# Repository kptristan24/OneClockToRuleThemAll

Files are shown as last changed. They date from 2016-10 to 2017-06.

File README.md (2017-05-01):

# OneClockToRuleThemAll
Our Senior Capstone Project to make a Word Clock on a budget. Weekly updates can be found on the wiki!

The project source code can be found in the sub directory [source/library/clean](source/library/clean)

## Usage Instructions

1. Aquire Necessary Hardware:
  * Arduino Uno (Other ATMEGA328 based boards may work but will probably take tinkering)
  * DS3234 RTC Module
  * Programmible LED strip supported by DOTSTAR library
  * Buttons
  
2. Assemble Hardware:
  * Connect the arrangement of LED strips, the RTC, and at least 3 buttons
  * There are many possible arrangements with the avaliable pins but where you connect things can be set in software.

3. Setup Software:
  * Download and install the latest version of the Arduino IDE (as of this writing: v1.8.2)
  * Some operating systems may require adjusting permissions of the tty interface

4. Setup Code:
  * Download a copy of the subfolder: source/library/clean
  * Download a copy of the libraries folder: libraries
  * Load the source code in Arduino IDE and include the RTC library and the FastLED library.
  * Edit the #define statements at the top of buttons.h, timekeeping.h, and display.h to set the pins where hardware is connected.
  * Plug the board in and flash the software

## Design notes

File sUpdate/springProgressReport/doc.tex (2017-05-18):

\documentclass[onecolumn, draftclsnofoot,10pt, compsoc]{IEEEtran}
\usepackage{url}
\usepackage{setspace}
\usepackage{graphicx}
\usepackage{xcolor}
\usepackage{textcomp}
\usepackage{listings}
\usepackage{geometry}
\lstset{
	language=C,
	keywordstyle=\bfseries\ttfamily\color[rgb]{0,0,1},
	identifierstyle=\ttfamily,
	commentstyle=\color[rgb]{0.133,0.545,0.133},
	stringstyle=\ttfamily\color[rgb]{0.627,0.126,0.941},
	showstringspaces=false,
	basicstyle=\small,
	numberstyle=\footnotesize,
	numbers=left,
	stepnumber=1,
	numbersep=10pt,
	tabsize=8,
	breaklines=true,
	prebreak = \raisebox{0ex}[0ex][0ex]{\ensuremath{\hookleftarrow}},
	breakatwhitespace=false,
	aboveskip={1.5\baselineskip},
  columns=fixed,
  upquote=true,
  extendedchars=true
}
\renewcommand{\lstlistingname}{Code Example}

\graphicspath{ {./exPics} }
\geometry{textheight=9.5in, textwidth=7in}

% 1. Fill in these details
\def \CapstoneTeamName{     One Clock to Rule Them all}
\def \CapstoneTeamNumber{       57}
\def \GroupMemberOne{           Tasman Thenell}
\def \GroupMemberTwo{           Tristan Hari}
\def \GroupMemberThree{         Scott Metzsch}
\def \CapstoneProjectName{      One Clock to Rule Them all}
\def \CapstoneSponsorCompany{   Oregon State University}
\def \CapstoneSponsorPerson{        Dr. Victor Hsu}

% 2. Uncomment the appropriate line below so that the document type works

\def \DocType{		%Problem Statement
				%Requirements Document
				%Technology Review
				%Design Document
				Progress Report
				}

\newcommand{\NameSigPair}[1]{\par
\makebox[2.75in][r]{#1} \hfil   \makebox[3.25in]{\makebox[2.25in]{\hrulefill} \hfill        \makebox[.75in]{\hrulefill}}
\par\vspace{-12pt} \textit{\tiny\noindent
\makebox[2.75in]{} \hfil        \makebox[3.25in]{\makebox[2.25in][r]{Signature} \hfill  \makebox[.75in][r]{Date}}}}
% 3. If the document is not to be signed, uncomment the RENEWcommand below
\renewcommand{\NameSigPair}[1]{#1}

%%%%%%%%%%%%%%%%%%%%%%%%%%%%%%%%%%%%%%%
\begin{document}
\begin{titlepage}
    \pagenumbering{gobble}
    \begin{singlespace}
        %\includegraphics[height=4cm]{coe_v_spot1}
        \hfill
        % 4. If you have a logo, use this includegraphics command to put it on the coversheet.
        %\includegraphics[height=4cm]{CompanyLogo}
        \par\vspace{.2in}
        \centering
        \scshape{
            \huge CS Capstone \DocType \par
            {\large\today}\par
            \vspace{.5in}
            \textbf{\Huge\CapstoneProjectName}\par
            \vfill
            {\large Prepared for}\par
            \Huge \CapstoneSponsorCompany\par
            \vspace{5pt}
            {\Large\NameSigPair{\CapstoneSponsorPerson}\par}
            {\large Prepared by }\par
            Group\CapstoneTeamNumber\par
            % 5. comment out the line below this one if you do not wish to name your team
            %\CapstoneTeamName\par
            \vspace{5pt}
            {\Large
                \NameSigPair{\GroupMemberOne}\par
                \NameSigPair{\GroupMemberTwo}\par
                \NameSigPair{\GroupMemberThree}\par
            }
            \vspace{20pt}
        }
        \begin{abstract}
        % 6. Fill in your abstract
            The purpose of this document is to discuss the progress of the One Clock to Rule Them All project and what our team has done during the spring term.
Included is an explanation of each document updated during this period of time and a summary of the progress made during each week of the term.
In addition, this process is reflected in retrospective which discusses challenges and difficulties as well as progress.
        \end{abstract}
    \end{singlespace}
\end{titlepage}
\newpage
\pagenumbering{arabic}
\tableofcontents
% 7. uncomment this (if applicable). Consider adding a page break.
%\listoffigures
%\listoftables
\clearpage

% 8. now you write!
\section{Project Purpose and Goals}
The background of the product arises from the personal interest of our client, Victor Hsu.
While there are similar products already on the market, QWLock by Ziegert and Funk for example, these products suffer from high prices and low availability.
These items traditional occupy a designer market niche which doesn't allow most people to experience the ownership of one.
In addition to these problems, it is also difficult to track down a model that has english lettering, as Ziegert is based in Germany.

We are not the first group of people to be inspired by the unique aesthetic and function of the word clock.
There are plenty of DIY projects online that also attempt to solve the problems of price and availability.
While these projects have been a valuable source of insight for the project, they are often very complicated and considered outside the comfort level of our expected users.
The intention of this product is to improve upon the situation by making the creation of a word clock less expensive, simpler, or both.

The clock we are making will be completely self contained with a battery or wall plug being used to power the clock.
There will be a microcontroller that is used to control the LEDs on the display and interface with the RTC in order to provide accurate timekeeping capabilities.

On the side of the clock there will be 3 buttons that will be used to set the time on the clock and change features.
Each button provides a specific function depending on the software context.
An example of this system when a basic menu is being manipulated would have two buttons providing up and down scrolling and one button to select an option or submenu.

The microcontroller will be the central piece of hardware in our clock and have the software for running it embedded into it.
The RTC will be connected to the board through 6 ports and will be used to check the time periodically to verify that the time is still correct.
The LEDs will also be connected to the board and the microcontroller will send data to the LEDs that tell them which LEDs to light up.
Lastly the 4 buttons will be connected to the microcontroller to set time and access additional features added to the clock.

The clock will also provide a way for the user to set and edit alarms. While making an audible alarm wasn’t planned, user programmable alarms indicated by the display flashing are expected functionality.
Aside from that, all the other goals were simply that: it continues to operate in the normal range of temperature, at least a year straight, and is visible from 10-20 feet.

\section{Current State of project}

\subsection{Hardware}
In terms of hardware we have all of our electronic components working.
The Arduino Uno is working correctly and can communicate with the LEDs, RTC, and buttons.
The LEDs are all soldered together and have valid connections between the 12 strips.
We also have a power adapter with more amps that we are using to power both the board and LEDs.

In terms of the case hardware we are almost done with the case.
We have the 4 sides of the case cut to size with grooves cut for the front and back plate to slide in.
We have also stained these 4 sides.

\subsection{Software}
The current state of the software for the program is solid but needs more testing.
Due to difficulties relating to hardware assembly, large chunks of code have only been lightly tested.
That being said, feature completeness has been achieved and will be demonstrated during Expo.

The code is broken into two main components: the hardware abstractions and libraries, and example programs that use those libraries.
Each main hardware component (RTC, Buttons, and LEDs) are wrapped in abstractions which handle setting up these objects as well as facilitating ease of use.
Our example code is what presents the features described in our requirements to the user.

The core of the project is broken into a group of software libraries which are tied together in the main Arduino program loop.
These acts as the “operating system” of the clock from which different programs can be run, the running program can be changed, and alarms can trigger.

To get more detailed about this operating system comparison, each program for our system is a subclass of an abstract class called “state”.
All states share four common functions by which the operating system will interact with them.
The first of these functions is a constructor: a function which does any “run-once” setup for the program or state.

Three additional functions form the interface with between the operating system code and the running program: handleInput, runLogic, and drawFrame.
The first of these functions is tasked with dealing with user input.
The second function does any computing or processing work that needs to happen for the state.
The final function is tasked with updating the screen of the clock.
For some states this could be menu text, for others it could be the time in words, and for others it might be a digital time.

The second set of software written for our project is a set of example states.
These could be compared to Internet Explorer and MS Paint that come bundled with Windows.
These example states are a set of programs that run on top of the aforementioned set of abstractions which form the operating system for this product.

The example states (or programs) that are included in our project are geared towards meeting the software functionality requirements for our project.
Some of the states we have developed which will be shown off at expo are: normal word clock, digital clock, system menu, add/remove alarms, game of snake,  LED demo, and a triggered alarm.
Thanks to the high level abstraction offered by our hardware libraries, most of these states are relatively simple which was one of the goals of the project.

\subsection{Technology Review}
The technology review has been updated to reflect several changes in the project that have occured over the past two months.
The largest changes take the form of a change in the development board.
While the MPLABS Xpress board seemed like a good idea on paper, it didn't have much in the way of software support.
In addition to this, the documentation and code examples for the board were ranging from poor to nonexistant.

The new board chosen to replace it is an Arduino Uno.
This board has better software support and documentation by a very large margin.
This is documented in the Technology Review in the form of discussing the new board as well as the libraries that come with it.
Extensive research into libraries allowed development to progress more in two weeks than it had duing the six weeks prior.

\section{Remaining Work}
\subsection{Hardware}
Our remaining problem is that we are waiting for our final clock face cut from Kevin.
We should have started the prototyping process sooner to allow for more iterations of the case and clock face before we needed our final product.
Once we have the final test cut back from Kevin we will have all the hardware sections of the project completed.

\subsection{Software}
The largest remaining piece of work that needs to be done is debugging.
Various technical and cranial setbacks meant that we didn’t have a full set of the hardware assembled to test code on until somewhat recently.
Debugging is going well and is following the logical order of necessity: state manager first, display library second, time library third, and lastly button control.
That being said, all the core features are on course to be functional at Expo.

In addition to a scrolling text library, the code for static text needs to be finished.
This functionality allows the clock to show words of length four or less in fixed positions.
This was left until the end of development as scrolling text is significantly more complicated and static text can reuse most of the same code.

Another requested feature that won’t be complete for Expo is a color gradient generator.
This boils down to coming up with an algorithm that generates a unique color for the time of day.
The idea behind this capability is that the word clock (or other modes) can gradually shift through pleasant colors throughout the day.
The holdup here is an algorithm.
The function infrastructure is already in place.

Being able to change the simulated pace of time for the sake of demonstration is one feature we are rushing to complete before expo.
This will act as a wrapper around the get time functions in the clock so that we can accelerate the passage of time for the clock.
This would be useful for demonstrating alarms going off or the gradual change in color if that feature is ready by Friday.

Another item that remains on the “to-do” list is rewriting the alarm system to not rely on hardware alarms.
While using the hardware alarm feature on the Real Time Clock (RTC) can work fine, it would easier and cleaner to have alarms be handled in software.
This also frees the hardware alarms up for usage in project code without conflicting with clock functionality.
Another perk of this change would be that it makes it even simpler to port our project to a different RTC chip because we use less specific hardware features.

The last part of the project that needs to be completed before we turn our work over to our client is documentation.
Code interface has been commented to make it easy to interact with functions.
That being said, we need to produce a set of formal documentation about using our code as well as further documenting the example classes (programs) that run the basic clock functionality.
Documentation was set aside to get things ready for Expo which means it will need to be a top priority in the three remaining weeks after Expo.

\section{Impeding Factors}
Over the course of the project there were two major things that impeding progress for us.
The first of which is the original microcontroller we had.
The MPBLABXpress Evaluation board we started with looked appealing and had a nice demo example, upon further inspection we found that this was just a nice appearance.
Once we started looking into writing code to control a strip of LEDs we ran into many issues.
Large sections of the code is auto generated which made it difficult to understand and make edits to files.
Second the problem is that library integration was difficult to implement and we would be using multiple libraries to control the RTC and LEDs.
When we came to the conclusion that this board wasn’t going to work we decided to move to an Arduino Uno for our microcontroller.

The second main issue we had in our project was designing the case.
With all of us being CS students we have limited woodworking experience.
To get around this problem we created multiple prototypes and talked with people at lumber stores to learn about different techniques and wood we might use for the case.
With the multiple people and prototypes we made our final case has turned out great and has a nice finish and appearance.

\section{Code Samples}
\subsection{Scrolling Text}
\lstinputlisting[language=c++, caption=Scrolling text Example., captionpos=b]{codeExamples/demoState.cpp}
One of the key abstractions that powers the interface for the clock: scrolling text.
Our software supports two independent lines of text which can be set, cleared, and updated independently.
This was done in order to be able to show text that isn’t among the words cut into the clock faceplate.
One place this is crucial is for displaying menu text.
\vspace{5mm}
\subsection{Menu Code}
\lstinputlisting[language=c++, caption=Main Menu State., captionpos=b]{codeExamples/mainMenu.cpp}
Another core UI element in the menu.
For our system, a menu is composed of two sections: the menu title (displayed on the top row of text), and the menu options (displayed on the lower row).
Rather than having to right clusters of switch statements and other conditional logic every time a manu is needed, a menu item is provided.
This object does all the heavy lifting of displaying menus and handling user interaction.
\vspace{5mm}
\subsection{The "Operating System"}
\lstinputlisting[language=c++, caption=Core System Loop., captionpos=b]{codeExamples/clean.cpp}
Displayed above is the core code for running the clock.
A user of our software need not alter any of this, they only need to select the starting state of the clock.
The key pieces here are check for hardware signals (from buttons or RTC), run the current program, change the running program if required, and run cleanup to prepare for a new program.

\section{Project Pictures}
A few pictures from our development and work on the project.
\centering
\begin{figure}
\caption{Professional woodworking in progress}
 %natwidth=3024,natheight=4032
\end{figure}
\begin{figure}
\caption{Case parts prior to finishing}

\end{figure}
\begin{figure}
\caption{The scrolling text library showing "Hello" and "World"}
\vspace{2mm}

\end{figure}
\end{document}

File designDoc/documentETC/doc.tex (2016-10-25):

\documentclass[10pt,draftclsnofoot,onecolumn]{IEEEtran}
\newcommand{\namesigdate}[2][7cm]{%
\begin{minipage}{#1}
    #2 \vspace{1.0cm}\hrule\smallskip
    \small \textit{Signature}
    \vspace{1.0cm}\hrule\smallskip
    \small \textit{Date}
\end{minipage}
}
\usepackage{graphicx}
\usepackage{textcomp}
\graphicspath{ {} }
\begin{document}
\pagenumbering{gobble}
\title{One Clock To Rule Them All}
\author{Tristan Hari, Tasman Thenell, and Scott Metzsch}
\maketitle
\begin{abstract}
Historically, the wristwatch has had one of two faces, analog or digital. These
formats have provided a solid mix between function and fashion, but there are
many other possible ways of visually representing the concept of time. One
creative idea worth exploring is timekeeping through words and letters. The
basis of our capstone project is to investigate making such a clock with a
microcontroller, real time clock module, and a set of LED’s. We will combine
this physical base with a software library of our creation to power a word clock.
\end{abstract}
\IEEEpeerreviewmaketitle

\newpage
\pagenumbering{arabic}

\title{Problem Statement}
\section{Problem Background}
Timekeeping isn\textquotesingle t an advanced concept at a fundamental level. Since the first
cavepeople noticed that they had to shade their eyes from the sun differently
at various ``times'' of the day, humans have studied time. Throughout history
humans have created many different methods for tracking time. , each more
ostentatious than the last, for keeping time. Classic examples of the lengths
cultures have gone to track time include Stonehenge and Big Ben. While such
methods of timekeeping aren\textquotesingle t necessary, we still seek even more
interesting ways of telling time. One such example of this is the word clock. A
word clock has a face made out of a grid of letters. This grid is layed out such that
there are enough letters to create all words required for spelling out any given time
of day. While clocks following this idea already exist, most are overly complicated,
look chintzy, or are prohibitively expensive.

\section{Problem Solution}
We would like to address the problem of this type of time keeping solution not
being readily avaliable by creating a similar product using
off the shelf parts and our own custom software. The current concept for
implementation is to use a microcontroller, real time clock (RTC), and LED strips
with individually programmable lights to power the face of the clock. For the
casing/shell we will investigate the feasibility of using 3D printing, laser cutting,
or woodworking to create structural components. In addition to the hardware, we
will develop a software library to run on the microcontroller that supports
various modes of displaying time as well as providing any additional functionality
we have time to develop.

\section{Metrics for Completion}
In order to demonstrate completion of this project, we will meet the following requirements:
\begin{itemize}
  \item Establish a connection between a real time clock module and a
  microcontroller for the purpose of controlling a custom clock face.
  \item Design a grid of letters such that there are enough of each letter for displaying
  all of the words necessary for spelling out any time of day.
  \item Support for an alternate output mode for displaying the time in binary coded
  decimal (BCD) mode.
  \item Take at least one source of input to facilitate letting the user set the
  time on the clock.
\end{itemize}

\section{Stretch/Additional Goals}
If time permits, our group will explore additional features that would either
make the clock more robust or easier \quad to use. The following stretch goals have
already been discussed:
\begin{itemize}
  \item Wireless or bluetooth methods for setting or changing the clock remotely,
  possibly via a mobile app.
  \item Support alternate physical configurations or letter grid arrangements.
  \item Different view modes that use the eleven by eleven grid of letters as an
  eleven by eleven pixel low resolution screen.
\end{itemize}

\newpage
\newpage

\noindent \namesigdate{Victor Hsu} \hfill \namesigdate{Tristan Hari} \par
\vspace{2cm}
\noindent \namesigdate{Tasman Thenell} \hfill \namesigdate{Scott Metzsch}
\end{document}

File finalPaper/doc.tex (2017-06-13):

\documentclass[onecolumn, draftclsnofoot,10pt, compsoc]{IEEEtran}
\usepackage{graphicx}
\graphicspath{ {graphics/} }
\usepackage{url}
\usepackage{setspace}
\usepackage{xcolor}
\usepackage{textcomp}
\usepackage{listings}

\usepackage{geometry}
\geometry{textheight=9.5in, textwidth=7in}

\setcounter{secnumdepth}{4}
\setlength{\parindent}{0em}
\setlength{\parskip}{1em}

\setcounter{secnumdepth}{4}
\setlength{\parindent}{0em}
\setlength{\parskip}{1em}

\lstset{
		language=C,
		keywordstyle=\bfseries\ttfamily\color[rgb]{0,0,1},
		identifierstyle=\ttfamily,
		commentstyle=\color[rgb]{0.133,0.545,0.133},
		stringstyle=\ttfamily\color[rgb]{0.627,0.126,0.941},
		showstringspaces=false,
		basicstyle=\small,
		numberstyle=\footnotesize,
		numbers=left,
		stepnumber=1,
		numbersep=10pt,
		tabsize=8,
		breaklines=true,
		prebreak = \raisebox{0ex}[0ex][0ex]{\ensuremath{\hookleftarrow}},
		breakatwhitespace=false,
		aboveskip={1.5\baselineskip},
		columns=fixed,
		upquote=true,
		extendedchars=true
}
\renewcommand{\lstlistingname}{Code Example}

% 1. Fill in these details
\def \CapstoneTeamName{		One Clock to Rule Them all}
\def \CapstoneTeamNumber{		57}
\def \GroupMemberOne{			Tasman Thenell}
\def \GroupMemberTwo{			Tristan Hari}
\def \GroupMemberThree{			Scott Metzsch}
\def \CapstoneProjectName{		One Clock to Rule Them all}
\def \CapstoneSponsorCompany{	Oregon State University}
\def \CapstoneSponsorPerson{		Dr. Victor Hsu}

% 2. Uncomment the appropriate line below so that the document type works
\def \DocType{		%Problem Statement
				%Requirements Document
				%Technology Review
				%Design Document
				Final Progress Report
				}

\newcommand{\NameSigPair}[1]{\par
\makebox[2.75in][r]{#1} \hfil 	\makebox[3.25in]{\makebox[2.25in]{\hrulefill} \hfill		\makebox[.75in]{\hrulefill}}
\par\vspace{-12pt} \textit{\tiny\noindent
\makebox[2.75in]{} \hfil		\makebox[3.25in]{\makebox[2.25in][r]{Signature} \hfill	\makebox[.75in][r]{Date}}}}
% 3. If the document is not to be signed, uncomment the RENEWcommand below
\renewcommand{\NameSigPair}[1]{#1}

%%%%%%%%%%%%%%%%%%%%%%%%%%%%%%%%%%%%%%
\begin{document}
\begin{titlepage}
    \pagenumbering{gobble}
    \begin{singlespace}
    	%\includegraphics[height=4cm]{coe_v_spot1}
        \hfill
        % 4. If you have a logo, use this includegraphics command to put it on the coversheet.
        %\includegraphics[height=4cm]{CompanyLogo}
        \par\vspace{.2in}
        \centering
        \scshape{
            \huge CS Capstone \DocType \par
            {\large\today}\par
            \vspace{.5in}
            \textbf{\Huge\CapstoneProjectName}\par
            \vfill
            {\large Prepared for}\par
            \Huge \CapstoneSponsorCompany\par
            \vspace{5pt}
            {\Large\NameSigPair{\CapstoneSponsorPerson}\par}
            {\large Prepared by }\par
            Group\CapstoneTeamNumber\par
            % 5. comment out the line below this one if you do not wish to name your team
            %\CapstoneTeamName\par
            \vspace{5pt}
            {\Large
                \NameSigPair{\GroupMemberOne}\par
                \NameSigPair{\GroupMemberTwo}\par
                \NameSigPair{\GroupMemberThree}\par
            }
            \vspace{20pt}
        }
        \begin{abstract}
        % 6. Fill in your abstract
        	The purpose of this document is to discuss the final state of the One Clock to Rule Them All project.
Included is the original version of each  development document, the changes made to these documents, and weekly development summaries for the past nine months.
In addition, this document includes project usage information and hindsight gained from development.
        \end{abstract}
    \end{singlespace}
\end{titlepage}
\newpage
\pagenumbering{arabic}
\singlespacing
\tableofcontents
% 7. uncomment this (if applicable). Consider adding a page break.
%\listoffigures
%\listoftables
\clearpage
\onehalfspacing

\section{Introduction}

The One Clock to Rule Them All project grew out of a desire to make DIY word clocks easy to build, control, and customize.
The client behind this vision was Dr. Hsu, an Oregon State research faculty working in biophysics. Outside of his research work, Dr. Hsu is a DIY electronics hobbyist.
Within the wide range of popular electronics projects is the area of timekeeping, and within those projects lies the word clock.

The idea of making a word clock isn’t a new idea.
Word clocks have existed in several forms in the past including designs that have generic displays capable of showing any word, to matrix displays of composed of predefined letters which can only show specific words.
Our client found the second layout of interest and was inspired to build one.
And this is when a difficulty arose.

There are several existing sets of code for powering word clocks already on the internet.
The difficulty is that all the existing code is built for a specific set of hardware and the software isn’t very abstracted.
For comparison, existing implementations are typically composed of several hundred lines of code.
Our finished software library can run a word clock with only around a dozen lines of code more than an empty Arduino project file.

It was this goal of making the software experience of building a wordclock less painful, more abstracted, and more user friendly that Dr. Hsu came up with this Capstone project.
Once we were placed with this project, our development roles shook down to the following: Tasman Thenell was the primary code architect, Scott Metzsch became the lead materials engineer, and Tristan Hari was the primary external interactions manager.

The other indispensable honorary member of our development team was Dr. Hsu himself.
While it was never formally set up that he would be part of the team, there were many areas of the project outside of coding where his consulting was invaluable.
While each of us brought strengths to the table around code development, Dr. Hsu was deeply knowledge about most of the other parts of our project.
Our development was greatly accelerated by picking his brain about electronics, materials, and other physical parts of development several times each quarter. Without this assistance, it is doubtful that the project would have been finished in time or achieved the same level of quality.

\section{Requirements Document}
\subsubsection{Purpose}
Historically, the clock face has had one of two display modes, analog or digital.
These formats have provided a solid mix between function and fashion, but there are many
other possible ways of visually representing the concept of time. One creative idea worth
exploring is timekeeping through words and letters. Although some examples of this already
exist in the high end fashion market, such as QWLock or others, they are well outside the
price range of an average consumer. The purpose of our project is to provide a similar
product with much cheaper production.

\subsubsection{Scope}
The name of our product is tentatively “One Clock To Rule Them All”, or “The One Clock.”
The One Clock’s function will be, simply, to tell time. However the functionality of it is
defined as being able to creatively tell time through a grid of apparently random letters.
Time will be displayed in forms such as “It is half past twelve” or “it is one fifty.” The
user will be able to set the starting time using a button component on the clock. Something
that may be assumed as a regular clock function that our clock will not do, is that this clock
 is not centered around being an alarm/scheduler device. We do not intend to have any sound
 components and thusly any alarm system will be mostly moot.

\subsubsection{Definitions}
\begin{enumerate}
  \item Time - The abstract concept that our machine is keeping track of and displaying to the user
  \item Real Time Clock - A real time clock module is the hardware component that tracks the passage
  of time regardless of the state of the rest of the system.
  \item RTC - Acronym for Real Time Clock module.
  \item Microcontroller - The brains of the clock. This module interfaces between the hardware
  components, the RTC, LEDs and buttons, and processes the logic for all clock functionality.
  This includes tasks like updating the display and processing user input from the buttons.
  \item Programmable LED - A Light Emitting Diode that has variable levels of brightness and
  color output. Each module is individually programmable in terms of brightness and color.
  \item LED - Acronym for Light Emitting Diode. Within this project, the term LED will always
  be used to refer to a programmable light emitting diode.
  \item Display - The LED lit letters of the clock face in a grid arrangement are collectively
  called the display. This term will be used to refer to the visual
  \item Software Library - The set of control software running on the microcontroller which drives all display output.
  \item User Interface - A set of buttons by which the user controls and interacts with the clock.
  \item BCD - Acronym for Binary Coded Decimal.
  \item Binary Coded Decimal - A method for encoding decimal numbers and information via binary.
  \item USB - Acronym for Universal Serial Bus.
  \item Universal Serial Bus - A communications medium by which the device is programmed and  powered.
\end{enumerate}

\subsubsection{Overview}
The following subsections of this requirements document describe product specifications as follows.
subSection 2 explains the purpose, function, and form of the product in broad terms on a less
technical level. Building on that foundation, subSection 3 breaks the functional requirements
describe in subSection 2 into technical requirements and specifications.
    Both of the following subsections are intended for conveying the entire functional
scope of the Word Clock project but at different levels. subSection 2 provides an overview of the
project while subSection 3 pertains to exact requirements which requires a more technical working
knowledge of hardware and software design.

\subsection{Overall Description}
\subsubsection{Product Perspective}
The clock we are making will be completely self contained with a battery
or wall plug being used to power the clock. There will be a microcontroller that is used to
control the LEDs on the display and interface with the RTC in order to provide accurate
timekeeping capabilities.

On the side of the clock there will be 4 buttons that will be used to set the time on the
clock and change features. Each button provides a specific function depending on the software
context. An example of this system when a basic menu is being manipulated would have two
buttons providing up and down scrolling, one button to select an option or submenu, and the
last button serving as a back or exit button.

The microcontroller will be the central piece of hardware in our clock and have the software
for running it embedded into it. The RTC will be connected to the board through 6 ports and
will be used to check the time periodically to verify that the time is still correct. The LEDs
will also be connected to the board and the microcontroller will send data to the LEDs that
tell them which LEDs to light up. Lastly the 4 buttons will be connected to the
microcontroller to set time and access additional features added to the clock.

\subsubsection{Product Functions}
Expected functionality related to standard clock features is known at this time
but other possible features have yet to be determined. A vague reference to these
future items is listed as the last function but no requirements for this item
is included in subsection 3.
\begin{enumerate}[a)]
  \item The main function of the clock will be to tell time through words displayed on the face of the
clock. Examples of the output format include “it is a quarter past twelve”, “it is a quarter to
five.”
  \item The clock shall provide a way for the user to set and edit alarms. While
  making an audible alarm isn't planned, user programmable alarms indicated by
  the display flashing are expected functionality.
  \item Additional functionality includes the possibility of adding extra features to the clock such as
color changes to tell the time of day, differences in brightness, and other features whose
development is purely contingent on time constraints.
\end{enumerate}

\subsubsection{User Characteristics}
Users of this product are expected to fall into two categories. While that might
seem to over generalize things, users break down cleanly into two categories.
The first is normal users who are just using this product as a clock. The second
type of user is the poweruser who might want to tinker with the software and
hardware of the clock in order to understand or expand upon it.
\begin{enumerate}[a)]
  \item A normal user is expected to be able to read, tell time and use a manual.
  \item Developers are expected to have the skills of a user as well as knowing the
capabilities of the hardware interfaces and the microcontroller in addition to
any skills necessary for software development.
\end{enumerate}

\subsubsection{Constraints}
The project needs to be meet a small set of physical and architectural constraints. These
constraints center around the units ability to act like a traditional clock in a reasonable
amount of space.
\begin{enumerate}[a)]
  \item The product must be accurate over the course of the year.
  \item The system needs to be compact enough to fit in a normal wall clock.
  \item Power shall be supplied via a conventional micro USB feed.
\end{enumerate}

\subsection{Specific Requirements}
\subsubsection{External Interface}
A set of 4 buttons provide the only interface to the software. These buttons
allow access to interacting with any available software menus. This is the only
point of contact between the user and the software.

\subsubsection{Functions}
The following items break down the general concepts of acting like a clock into individual
components of functionality. Together these functions are the software side of
how this product will be able to act like a clock.
\begin{enumerate}[a)]
  \item The system shall offer the user the ability to set the time via a
  physical interface.
  \item
  The system shall allow for setting, modification, and viewing of alarms.
  \item
  The system shall provide a visual indicator of an alarm going off but will not
  provide any auditory notification.
  \item
  The system shall recover from any series of inputs via the four button
  interface. Any input from other sources is considered unsupported and may result
  in undefined behavior.
  \item
  The system shall provide a menu option for switching output mode into BCD as
  well as a method for returning from BCD to the normal word output mode.
  \item
  The system shall update the time displayed every minute but the time in words
  shall be updated only every five minutes.
  \item
  The system shall provide a visual indicator for single minute increments of
  time.
\end{enumerate}

\subsubsection{Performance Requirements}
\begin{enumerate}[a)]
  \item The clock shall update the time being displayed within a second of the
  time in minutes changing.
  \item The clock shall not lose more than .432 seconds of accuracy per day.
  \item The system shall maintain this accuracy regardless of the presence of
  power for at least nine years, the lifespan of the RTC internal battery.
\end{enumerate}

\subsubsection{Physical Requirements}

\begin{enumerate}[a)]
  \item The system components, not including the clock housing, shall weigh no
  more than 5 pounds.
  \item The display shall be legible at a range of up to 10 feet for users with
  typical visual acuity, roughly equivalent to a 20/20 rating.
  \item The clock shall operate with the accuracy described in subsection 3.3.2 and
  3.3.3 within the temperature range of 0 degrees to 85 degrees fahrenheit.
  \item The grid of letters used to display the time will be no smaller than 10
  by 10 and no larger than 25 by 25 letters.
  \item The system shall be powered by a micro USB port.
  \item The system shall have four tactile buttons.
\end{enumerate}

\section{Gantt Charts}
\newpage
\subsection{Starting}
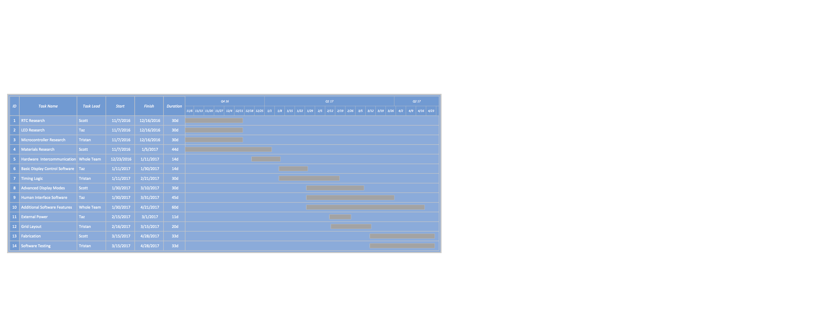
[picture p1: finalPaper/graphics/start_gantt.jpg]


\subsection{Ending}
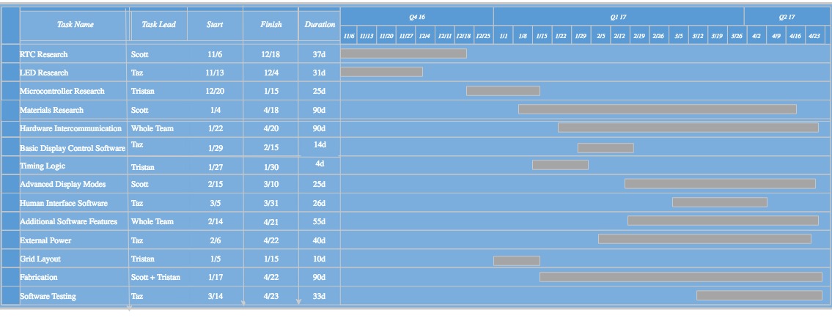
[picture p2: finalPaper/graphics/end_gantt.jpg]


\section{Requirements Document Changes}

\subsection{Table of Changes to Requirements Document}
\begin{center}
\begin{tabular}{| p{0.3\linewidth} | p{0.3\linewidth} | p{0.3\linewidth} |}
\hline
Requirement &
Original Requirement &
Final Product \\
\hline
Number of Buttons &
4 Buttons &
3 Buttons \\
\hline
Power Supply &
Power over USB &
Power from Barrel Adapter \\
\hline

\end{tabular}
\end{center}

\subsection{Explanation of Changes to Design Document}
There were only two significant deviations from the original set of requirements that were generated in the fall. While these changes do mean that our final product doesn’t match the letter of the requirements document, both changes were made for good reasons and didn’t result in a reduction of functionality. In actuality, one of the changes was necessary to maintain other promised functionality in the requirements.

The first change is the reduction in the number of physical buttons for controlling the clock. Our original concept for the design language of how users would interact with the clock software called for four buttons. One of these buttons, the back button, was eliminated because it was converted to a software menu option. This both simplified the hardware and made the menu interface for interacting with buttons in code more unified. This change doesn’t impact our ability to meet any other requirements that were established.

The most important change from the original requirements is how power is supplied to the clock. Keeping power delivery over USB would have been simple and this is what was in the draft requirements. During later development while working with the LEDS, we discovered that the amount of power we could pull over USB without the need for specialized hardware wouldn’t be enough to power 144 LEDS at a reasonable brightness.

A USB power supply was replaced with a traditional 5 volt barrel adaptor which powers all of the clock hardware. This also lets the user control the power draw of their project with ease. 144 LEDS at maximum brightness can draw up to 8.4 amps at 5 volts. Our version of the product shown off at Expo only supplied 4 amps so the clock was run at 45 percent brightness. The change to a barrel adaptor with a flexible range of power options was also necessary for meeting the 20 foot viewing requirement.

\section{Original Design Document}
\subsection{Scope}
This product will an improved experience for users seeking an interesting and unconventional timekeeping device.
It will provide a fashionable and affordable alternative to a class of product that is usually very expensive.
In addition to these goals, the product will also provide an opensource platform for users with the skills to modify the programming of the device.

\subsection{Purpose and Background}
The intention of this document is to breakdown the details of this project, including the steps we will take to complete it and the tools/methods we will use to effectively develop our product.
The metrics that we will use to measure product completion will also be included in this document, and will be referenced as we continue to develop throughout the year.
The background of the product arises from the personal interest of our client, Victor Hsu.
While there are similar products already on the market, QWLock by Ziegert and Funk for example, these products suffer from high prices and low avaliability.
Thses items traditional occupy a designer marker niche which doesn't allow most people to experience one.
In addition to these problems, it is also difficult to track down a model that has english lettering, as Ziegert is based in Germany.

We are not the first group of people to be inspired by the unique aesthetic and function of the word clock.
There are plenty of DIY projects online that also attempt to solve the problems of price and availability.
While these projects have been a valuable source of insight for the project, they are often very complicated and considered outside the comfort level of our expected users.
The intention of this product is to improve upon the situation by making the creation of a word clock less expensive, simpler, or both.

\subsection{Intended Audience}
The primary intended audience for this document is our client, Victor Hsu.
This document is intended to provide an approachable explanation to the project design to any inquiring individual.
That being said, it also includes enough detail to serve as a resource for individuals with low level background skills in electrical engineering or computer science who are intending on modifying the system.

\subsection{Definitions}
\begin{enumerate}[]
  \item Time - The abstract concept that our machine is keeping track of and displaying to the user
  \item Real Time Clock - A real time clock module is the hardware component that tracks the passage
  of time regardless of the state of the rest of the system.
  \item RTC - Acronym for Real Time Clock module.
  \item Microcontroller - The brains of the clock. This module interfaces between the hardware
  components, the RTC, LEDs and buttons, and processes the logic for all clock functionality.
  This includes tasks like updating the display and processing user input from the buttons.
  \item Programmable LED - A Light Emitting Diode that has variable levels of brightness and
  color output. Each module is individually programmable in terms of brightness and color.
  \item LED - Acronym for Light Emitting Diode. Within this project, the term LED will always
  be used to refer to a programmable light emitting diode.
  \item Display - The LED lit letters of the clock face in a grid arrangement are collectively
  called the display. This term will be used to refer to the visual
  \item Software Library - The set of control software running on the microcontroller which drives all display output.
  \item User Interface - A set of buttons by which the user controls and interacts with the clock.
  \item BCD - Acronym for Binary Coded Decimal.
  \item Binary Coded Decimal - A method for encoding decimal numbers and information via binary.
  \item USB - Acronym for Universal Serial Bus.
  \item Universal Serial Bus - A communications medium by which the device is programmed and  powered.
\end{enumerate}

\newpage

\subsection{Design Context}
When designing software for our clock we will be influenced heavily by the hardware components that we were given.
Our code will have subsections written specifically for use with these intended components since the microcontroller, RTC, and LED strips all have specific ways they want data transfered.
These hardware requirements will have to be taken into account if someone is using different components to create our word clock.

\subsection{Design Concerns}

For our clock the main concerns are to be able to read the clock and make sure that it is accurate and does not lose time.
We will also be concerned the clocks ability to maintain power and charge effectively.
This will of course affect the main concerns listed, but was worth mentioning on its own as it is it's own unit of the product separate from the pieces that will control readability and timekeeping.

\subsubsection{Functionality}
The time will be set through a physical interface of 4 buttons, the clock will be able to recover from any set of presses from these buttons.
Through these buttons you will be able to set a visual alarm and switch the display mode to BCD.
Also the design of the face of the clock should be able to be read from 10 feet away.

\subsection{Design Viewpoints}

We have selected three primary viewpoints from which to break down the design behind the requirements for the project.
The primary viewpoints are algorithmic, composition, and interface.
The algorithmic viewpoint was selected in order to discuss the accuracy and performance of the combination of the project hardware and our planned system software.
The composition viewpoint provides a space to describe the components of the project and how they interact, while the interface viewpoint describes user centric design components.

\subsubsection{Algorithm}
This subsection addresses some of our client's requirements about clock performance, BCD display mode, time loss per day, and the visual alarm.

\paragraph{Clock Performance}
\vspace{2mm} Design Concern: This addresses the design concern of being accurate and is primarily for the users.
The clock will need to be accurate or it is of zero worth as a clock.

\vspace{2mm} Analytical Methods: Simply comparing the clocks ability to remain accurate to another atomic based clock.
The time we have to exhaustively test this is limited and we will only at most be running 48 hour trials.

\vspace{2mm} Rationale: We decided that this viewpoint was important because it directly impacts the users experience.
Our client Victor Hsu would also consider this an important aspect as a measure of success in development of the clock.
In terms of the project Clock Performance and algorithm is entirely what determines the worth of the product, thusly making this a top priority in terms of viewing the project.

\paragraph{BCD Display Mode}
\vspace{2mm} Design Concern: This addresses the design concern of readability for the user.
Using the BCD display model is required for our project by its conception, and having the display properly lighting is paramount to the products success.

\vspace{2mm} Analytical Methods: Fortunately for this Concern, it is simply a matter of observation.
One would be required to view the clock for the entirety of a 24 hour day to exhaustively test this display, but short observation at AM PM times will be sufficient.

\vspace{2mm} Rationale: We decided that viewing the project from the BCD display perspective would be pertinent as it is what will be doing the entirety of the work for the display.
The BCD model needs to be 100\% functional for the user to read the clock, for the clock to be visible, and for the time outputs to be legible and correct.

\paragraph{Time Loss}
\vspace{2mm} Design Concern: When it comes to any solitary clock that does not sync atomically, accuracy will be lost over time due to the nature of time keeping in electronics.
This is an important concern as it once again addresses the clocks accuracy, in regards to accuracy loss over time.

\vspace{2mm} Analytical Methods: We will not have the ability to exhaustively test this, however we will be doing timing tests over short sessions to see if the time loss is accurate to the value given by the producers of the RTC.
Keyesstudio's website boasts that the clock will remain accurate within 0.1728 seconds per day, so over several days we will compare time loss with an atomic clock  and verify that the loss is within the acceptable range.

\vspace{2mm} Rationale: This viewpoint is pertinent to our project as a perspective of value of the clock.
A clock's worth is in ability to keep time accurately, and last for long periods of time.
Observing the clock from a time loss based perspective gives us an crucial outlook on the value of the end product.

\paragraph{Visual Alarm}
\vspace{2mm} Design Concern: This addresses the design concern of there being a visual alarm on the clock that does not make sound but has a visual queue that it is going off.

\vspace{2mm} Analytical Methods: Setting the alarm for a time and verifying that it goes off will be the majority of the testing required for this feature.
The test should be used after a test of the LEDs to verify that they are working correctly.
This way you can tell if a bug is caused by the LEDs or the code for the visual alarm.

\vspace{2mm} Rationale: We decided this viewpoint was important because it is a useful feature of clocks and a requirement of our product owner.
Victor Hsu was also interested in having an alarm of some type added to the clock since that is a basic function of most clocks now a days.

\subsubsection{Composition}
This subsection addresses some of our client's requirements about time loss per day, display modes, and clock controls.

\paragraph{Time Loss}
\vspace{2mm} Design Concern: This addresses the design concern of the clock being accurate over time which is important to the users.
The clock will need to be accurate and not lose the time when the clock is unplugged.

\vspace{2mm} Analytic Methods: Comparing the RTC time to the time of the microcontroller will be done every set amount of time to maintain accuracy and recover the time of the clock if there should be a power disconnect and the microcontroller loses the time.
Testing will be done though unplugging the microcontroller and then replugging the microcontroller to verify the time is still being kept.

\vspace{2mm} Rationale: This viewpoint is important to the design of the clock because it affects the easy of use and accuracy of the clock.
Victor Hsu would also consider time loss as an important aspect in the development and functionality of the clock.
In terms of time loss and composition, the RTC will be the main unit to keep time since there will not be any power interruptions with it's independent battery.
Also the RTC can then communicate the time to the microcontroller with wires so that there will always be a device keeping the time even in the event of power loss to the microcontroller.

\paragraph{Display Modes}
\vspace{2mm} Design Concern: This addresses the design concern of making the letters of the clock visible at 10 feet as well as being able to output the time in a BCD format.

\vspace{2mm} Analytics Methods: The LEDs are the main display and will allow the user to read the time based on the backlit letters on the face of the clock.
Testing will be done though a script that runs the LEDs through all colors and brightnesses as well as checking that each letter on the clock face is able to be controlled individually.

\vspace{2mm} Rationale: This viewpoint is important to the design of the clock because it affects the readability of the clock face and the letters that it is lighting.
Controlling the brightness and color of the clock will help to meet Victor's requirement that the clock should be visible from 10 feet.
These strips of LEDs will be connected to the clock through a set of wires that pass the data to the LED strips.

The other important concern being addressed is supporting BCD output mode.
Instead of powering a grid of letters, the BCD output mode is crucial for allowing the software suite to control other displays.
BCD is a generic format which could make our control software usable for a wide range of projects.
In addition to that, it also is very simple to test BCD formatting using something like a nixie tube.
\paragraph{Clock Controls}
\vspace{2mm} Design Concern: This addresses the design concern of the ability to control the clock and make changes to display settings and the time.

\vspace{2mm} Analytics Methods: The buttons will be connected to the clock through a set of wires for each clock and will be tested through pressing each button and verifying that the microcontroller gets the input.
The input types will be split in terms of a press or a hold of the button so that either can be used for possible input control.
This will test both the connection between the microcontroller and the LEDs and the LEDs themselves to make sure both are working correctly.

\vspace{2mm} Rationale: This viewpoint is important to the design of the clock because it affects the easy of use when choosing different settings for the clock LEDs or setting the time.
Victor would agree that having buttons that work and are accurate to their function is important to the design of the clock.
These buttons are the users main interface to interact with the device.
It is important that these buttons have no issues since the only other way to interact with the clock is through the microUSB port.

\subsubsection{Interface}
This subsection addresses our client's requirements about clock controls and ability to read the clock.
The interface is broken down into two perspectives: users and developers.
The user centric interface consists of a set of buttons for menu control while the developer interface consists of direct interaction with the microcontroller.
\vspace{1mm}
\paragraph{Clock Controls}

\vspace{2mm} The main design concern for clock controls was providing enough buttons for intuitive menu navigation without uneccesary complication.
A secondary design goal was to provide developers enough sources of input for any additional functionality.

\vspace{2mm} To meet these design goals, a layout of four buttons on the side of the clock has been chosen.
These buttons provide control over the planned interface scheme which is: a select button, a back button, and buttons for up and down scrolling.
An initial setup with only three buttons was considered but it did not make the interface simple enough from a user perspective.
The rational behind this was a desire to not have any button have more than one function in the core interface.
With the three button interface, that would have meant a contextual combination back and select button, or only scrolling in a single direction.

\vspace{2mm} From the developer perspective, four buttons also won out as it provides additional flexibility.
While it is not known at this time if all of these buttons will be necessary, the developer perspective is secondary to the user one.
That being said, giving additional flexibility for the physical interface for any custom project was deemed to be mostly a positive.
\vspace{1mm}
\paragraph{Clock Readability}

\vspace{2mm} While being able to control the product is important, an even larger concern was the legibility of the clock face.
The primary purpose of a clock is to provide convenient access to the time of day.
With any creative twist on timekeeping comes the concern that the creative aspects will get in the way of the core functionality.

\vspace{2mm} From the user perspective this design goal will be easy to meet.
Unlike other novel approaches to displaying time, our display doesn't require any additional thought or effort to acquire the time.
The whole idea behind a word clock is that reading the time is as simple as reading the words on the clock face.
The clockface spells out the time in words and reads like a sentence.

\vspace{2mm} While the display works very well from the user perspective for timekeeping, it comes with some large limitations for developers.
Unlike most other traditional displays, a letter based matrix is drastically lower resolution and does not use uniformly shaped pixels.
These concerns are secondary to user legibility but some choices have been made to help developers.
The current design calls for a grid which is fourteen by fourteen letters which is a larger resolution that most word clocks.
Providing a slightly higher resolution is the best we can do to help with the display of developer projects.

\vspace{1mm}
\paragraph{Developer Interface}

\vspace{2mm}
One final interface design goal was to cater to developers or users that would like to tinker with the clock software.
We would like to facilitate access to the control software without the need for expensive software tools or hardware modification.
These goals were taken into consideration when picking the board and this has lead to a flexible toolset that costs nothing.

\vspace{2mm}
This design goal has been one of the easiest to meet due to the choice of microcontroller.
The choosen controller has a standard hardware interface which comes in the form of a miniUSB port.
In addition to this, it also comes with a web based integrated developer environment which provides software developer tools with the need for downloading or purchasing software.
While most boards have accompanying software, on standard operating systems this board is plug and play and requires almost nothing in the way of drivers or additional setup.
These features of the microcontroller combined with making the default software open source should allow anyone who would like to tinker with the product or develop for it do so without much difficulty.

The other aspect of the chosen board that is conducive to development is the abundant supply of libraries and examples.
Having a product within the Arduino family of boards paves the way towards a numerous existing parts of software projects.
The process of adding hardware to the project for which there is already an Arduino library is usually as simple as including the library.
This level of software and hardware support combined with spare pins on the board should leave developers ample room for projects.

\section{Changes to Design Document}

During the course of development, several key changes were made to our original design.
Most of the changes were relatively minor and revolved around user interaction and the details of the interface.
The only major change that happened during development was moving to a different microcontroller and software platform.

This last change was made very early on in development and directly enabled the success of the project.
The initial plans called for using a very low end microcontroller board, the MPLabXPress board.
The hardware cost and software environment promised by this piece of hardware seemed in line with the project goals: inexpensive and easy to use.
While the board was cheap, the software side of things turned about to be anything but easy to use.

After several weeks of initial development and investigating getting the XPress board talking to the other components, it became clear that the documentation was very poor and that example code was lacking.
This was a newer board that hadn’t been used much for this type of project so this wasn’t very surprising.
After running into this headache, the choice was made to switch to the far more capable and proven Arduino ecosystem.
With this change, all the hardware was communicating within two days of receiving the new board.

The other deviations from the original design that are worth discussing are the changes made to the controls for the clock.
The original set of designs we came up with called for 4 buttons for ease of use: up, down, select, and back.
During development it became clear that there wasn’t a need for a hardware back button for two reasons.
Not all interfaces needed it and it could easily be replaced with a software menu option.

The second interface change came in eliminating using button press duration to indicate different things.
Once our software menu code became robust enough, any need for specialized functions controlled through long button presses was eliminated.
Maintaining a uniform control design language that relied on menus and options was determined to be more user friendly and had a lower learning curve.

The combination of these interface changes makes using the default interface more simple and makes it easier to interact with buttons via code.
The button software library handles button interaction and reduces the complexity down to a single line for asking if a button has been pressed.
This wasn’t possible when there were multiple ways of pressing the same button as described in the original design.

\section{Technology Review Document}
\subsection{Micro Controller}
The technology we are using for our micro controller is the MPBLABXpress Evaluation board.
The reason why this will be our sole selection is simply that it is what was chosen for us to use by our client.
That being said it is an excellent choice.
There are many projects that have been created using this micro controller, from things like other clocks, to home monitoring systems.
It has many pins for usage and runs very efficiently with power. The creators also provide a cloud based IDE \cite{cloudIDE} that is very easy to use and load new programs onto the board with, which is a feature exclusive to the board we are using.
A few of the competing products on the market right now is the Adafruit trinket \cite{trinket} mini micro controller, and the infamous raspberry pi \cite{pi}.
The Adafruit device is excellent as it is very small and can do all of your favorite 5v logic programs.
The only issue faced with this device in the light of our project is that it does not have enough power throughout capabilities to properly control the LED array that we will be using.
Also it would require some sort of board to be placed on, and that would lead to additional hardware needing to be bought, and potentially increasing the size past where we would have liked it.
The raspberry pi is also an excellent product. There and thousands of project examples that are out there for the pi as is.
The only reason we decided not to proceed with the raspberry pi is mainly that is more than what we need.
The raspberry pi is an entire tiny computer that can run Linux flavors and do many things.
But with that in mind, they are much more expensive as are the parts to expand the capabilities.

\subsection{RTC}
We are working to create a clock that will tell time with words instead of hands or numbers.
To keep track of the time we will be using a real time clock module that is powered by a battery to keep track of the time so that even if the clock loses power time will still be kept track of.
We will be using the RTC module to know when to update the face of the clock to show a new time.

For our project Victor has supplied us with 3 KeyeStudio DS3231 Clock Modules.
The RTC is powered by a small battery that will keep track of time even if the main power source is turned off or disconnected.
The main benefit of this clock is that is has an integrated temperature-compensating crystal oscillator and that there are pins we can attach wires to instead of having to solder each wire to the board.
In RTCs time is kept by using a small quartz crystal that has a resonance of a precise frequency.
This frequency is used to keep track of time and there can be small changed based on the temperature that the crystal is at.
In our RTC there is an adjustment made that will allow us to get more accurate time keeping when the RTC is within recommended temperatures.
Between 0 degrees Celsius and 40 degrees Celsius the clock is accurate to 2ppm \cite{ksRTC}, or in other words it will have two errors every 1 million seconds.
With this accuracy we will only lose around 0.1728 seconds per day or 63.072 per year.

An alternative to the KeyeStudio RTC is the SparkFun Real Time Clock Module.
Compared to the KeyeStudio RTC the SparkFun RTC has two main weaknesses, the first is that the clock is not have any crystal temperature correction and does not have pins to connect wires into.
Not having crystal temperature correction has main issues when you have your clock changing temperatures with the weather and seasons.
The SparkFun RTC has an advertised accuracy of 20ppm which is 10 times the errors that you have in the KeyeStudio RTC.
A 20ppm error will lead to 1.728 seconds loss over a day and 630.72 or 10 minutes 30 seconds over the course of a year.
This lack of temperature correction is a strike against the SparkFun RTC.
The second weakness of the SparkFun RTC is the lack of built in pins for connecting the RTC to the logic board.
The intent of the SparkFun RTC is to solder wires onto the RTC and then to the logic board to connect the two parts, but with SparkFun RTC being only 20mmx20mm and roughly the side of a quarter \cite{sfRTC} soldering 5 wires onto the board can be slightly difficult.
Also having pins instead of soldering wires to boards makes it easier to fix mistakes make connecting the correct wire to the correct place on the logic board.

A third option for the RTC could be the SparkFun DeadOn RTC Breakout, this RTC has some advantages over the SparkFun Real Time Clock Module but still is behind the KeyesStudio RTC in terms of ease of instillation.
The SparkFun DeadOn RTC is similar to the KeyesStudio RTC since they both have a temperature-compensated crystal oscillator to keep track of time, this reduces the error to 2ppm \cite{sfDeadOn} from 20ppm with the non-temperature-compensated SparkFun RTC.
But where the SparkFun DeadOn RTC is still behind the KeyesStudio RTC is in connectivity.
With the DeadOn RTC you still need to solder wires onto a board the size of a quarter, but instead of 5 wires there are 7 connections on the DeadOn RTC.

For our project Victor made a great choice for the RTC.
The KeyesStudio RTC is accurate, easy to connect to the board, and the cheapest of the 3 boards coming in at \$6.80 on KeyesStudio’s store page.
With the KeyesStudio RTC winning in all 3 categories that have importance to our project, (connectivity, accuracy, and price), it is the correct RTC to choose for our project.

\subsection{Fabrication Tools}
To create the case of our clock we have many tools, but the main 3 we are looking at using are a 3d printer, laser cutter, and CNC.
Each tool has its strengths and weakness that will impact our decision on what to use for all the different parts that will go into our clock.

The first tool we can use for our project is a 3d printer.
Most modern 3d printers use either ABS (Acrylonitrile Butadiene Styrene) or PLA (Polylactic Acid) which are both thermoplastics.
3d printers create objects by melting down this plastic and applying layer after layer to form the walls and internal lattice of the object.
In the settings of the 3d printers you are able to change the thickness of the walls and pattern that the machine prints for the hollow inside the object.
Both the wall thickness and internal pattern determine the strength, weight, and robustness of the object as well as increasing of decreasing the time it takes to print the object. Each 3d printer also has a limitation that comes from the size of the printing area.
We imagined our clock to be around 12 inches by 12 inches and most 3d printers would not be able to print pieces that large and if they were able to it would take a very long time to print.
3d printing can be used in our project for any parts we may need that are not easily found at a hardware store or are not flat objects.
We envision possibly using the 3d printer to help create mounting point for the micro controller, guides for LED strips, or other small parts we find cannot find at hardware stores.

The second tool we are able to use for our project is a laser cutter.
Many laser cutters use a laser beam and focus the beam to create a focus point that can melt, burn, or vaporize the material at the focus point.
The process is similar to using a magnifying glass to focus the sun onto burn objects.
Laser cutters are good for cutting acrylic, wood, and if powerful enough can cut metals.
Consumer laser cutters like the ones we have access to are usually limited to cutting plastics and woods.
Since laser cutters cut using heat and concentrated beams there is a great deal of heat generated during the process and this needs to be accounted for when choosing materials and thicknesses of materials.
Thicker materials or harder woods need to be cut at slower speeds and thus cause the material to heat up more and can leave burn marks and can warp the material you are cutting.
There is some marking techniques and cooling tools that help to reduce the amount of heat and burning that can affect the cut of a material.
We envision using a laser cutter if we want to make the housing of our clock acrylic or out of a softer or thiner pieces of wood.

The last tool that we have access to is a CNC (Computer Numerical Control) router.
CNCs use specific types of drill bits to cut materials out and create 2d or 3d shapes.
CNCs are very similar to laser cutters in their cutting process but CNCs have the benefit of generating less heat to make to remove material.
Similar to the laser cutter the cut speed depends on the hardness of the material and the speed and depth of the cut need to be adjusted accordingly.
If your material is a soft wood like pine, you will be able to have each pass of the CNC be faster and/or deeper compared to if you are a harder wood like maple or oak.
We envision using the CNC router to create the face and back of the clock.
It will be a good tool to cut out each letter on the face of the clock and for removing material from the back to isolate the light from each letter.

Each tool that we have access to can be used in our project and each has strengths and weaknesses over the other tools.
We will use either the laser cutter or CNC for most of the large pieces of the clock since they are faster than the 3d printer, and the 3d printer will be perfect for small pieces or mounting hardware of electronic components.

\subsection{Materials}
For our project we have 3 possibly types of materials to use for the case of our clock, acrylic, wood, and ABS/PLA.
Each material will have strengths and specific uses in our project.

One possible materials we can use in our clock is acrylic.
Acrylic is a plastic that you can purchase in sheets or different colors, varying thickness, and physical characteristics.
Proposed uses of acrylic are the face of the clock and case of the clock.
Side panels and the face of the clock would be easy to cut with either the laser cutter or the CNC.
We could also choose an acrylic that is opaque and this will help to isolate light from the LEDs from bleeding into other letters on the clock.
If we wanted to show off our cable management and electronics that go into our clock, transparent acrylic can be a great choice.
Acrylic can also come in mirrored sheets that can create unique ways to display the words on the face of the clock.
The one concern with using acrylic is that mounting objects to it could be a little difficult.
Mounting parts and components to an acrylic clock case would have to be done with glues since drilling and screwing into acrylic has a tendency to crack or split the material if done improperly.
Acrylic is also versatile in that we would be able to cut it with either the laser cutter of using the CNC if we find the correct bit and are careful not to crack the sheet.

Wood is another material that we have thought about using to create the case of the clock.
There are many options and choices of woods that we can choose for this project.
Cheaper or softer woods are a good choice for prototyping stage of the project since they are easier to cut and decrease the price of each prototype version. Hardwoods are a good choice for the final product because of their durability and aesthetic appeal.
The downside is that the cut time of hardwoods will be greater and the price can be more expensive compared to softer woods.
Woods will be easier to mount components into since we are able to drill into the woods with more confidence that the material will not split or crack.
Depending on the hardness of the wood we will be able to use either the laser cutter or the CNC to cut out the case of the clock.

ABS and PLA are popular thermoplastics used in filament 3d printers and can be used to print out small parts needed for our clock.
These plastics are heated up by the 3d printer, extruded, and then cool back to a solid state.
ABS filament is better when strength, flexibility, and higher temperature resistance are important to the object, while PLA has higher printing speeds, thinner layers, and sharper printed corners.
We intend to print small parts and mounting hardware for our clock so either ABS or PLA would meet the requirements we need of the part.

For the case of the clock we will be either choosing wood or acrylic for the body and face of the clock.
In both scenarios we will use a cheaper material for prototyping of the clock and then choose a more premium material for the final product.
ABS or PLA will be used for mounting hardware and any other small parts that we need to create our clock.

\subsection{Letter Grid Layout}
When looking at the grid layout there are infinite possibilities to pursue for what could be considered “optimal” or the best for our design.
That being said we will be comparing a few existing layouts for their potential of different displays.
The first one being the most popular, and one of the basis ideas for our project, the QWLock \cite{QWLock}.
The way their layout is, is to have each row with cascading potential priority in sentence structure to tell the time correctly.
So they have created in layers the exact words needed to spell out the correct time in the correct order.
Also They have whole words connected, not leaving spaces between letters.
This was a design decision to make the end product more legible but less apparently random and scattered looking while unlit.
A second grid design was one we found on an Adafruit tutorial page \cite{smallgrid} that was centered around a micro layout.
This one was only 8x8 layout, using the absolute minimum words and letters possible to communicate the time.
This was a creative design, however it loses the ability to tell time in five minute intervals, which would inherently break one of our requirements, so we will not proceed with a letter grid like this one, and will require more space than 8x8.
Another layout design was by Mike Gualtieri \cite{mikegrid}, who listed out some instructions about how to do a layout with any words of your choosing, and how to organize them in a good hierarchical fashion.
This is likely to be the method we will use to proceed, as following Mike’s “layout” algorithm is not only open source and free to apply, but allows us the freedom of word choice and layout.
The only constricting piece to this method is that it doesn’t strictly adhere by any means to letter by letter layout, or by ending in a square grid.
To achieve that may require some additional work on the method.

\subsection{Light Emitting Diodes}

One of the crucial parts of the clock is providing an interesting and legible clock face.
In order to achieve these goals, light emitting diode (LED) backlighting has been chosen to illuminate the letters of the clock face.
Using LEDs isn’t as simple as just choosing a type of light bulb, there are a strict set of requirements the final selection will have to meet.
To this end, we have selected three types of LEDs to test against the following requirements.

The LED requirements center around brightness, ease of use, flexibility, and power requirements.
The display is required to be readable at 10 feet but without using an amount of power that would require adding additional separate power supplies.
In addition, to facilitate being a programmable display, each LED needs to be separately controllable in a way that isn’t overly complicated.
Lastly, flexibility is desired as several stretch goals call for various color capabilities as well as brightness control.

The first type of LED under consideration is a small LED strip purpose built as a back light.
An example of this product can be found on Adafruit with product ID 1626. \cite{led1}
The entire module is a thin LED sandwiched in diffusing material that creates a small strip of light rather than a single distinct point.
These strips score well in power requirements, using only 20mA at around 3 volts but don’t provide many of the other desired features.
These modules don’t contain any internal brightness control, lack the ability to produce different colors, and would require the creation of a custom addressing system to allow for individual programming.

The second type of light being reviewed is a programmable RGB seven segment display (Adafruit ID 1399). \cite{led2}
These units provide several features that would be helpful for the project including flexible color and brightness.
The color capabilities are particularly intriguing because one planned feature is a having the clock face have a gradient of colors to shift through based on time of day.
The other specifications of these display units pose some of the same problems as the LED backlight described above.
While these have individual control capabilities, they require twenty one pins for a full range of control per display unit.
In addition to the complicated wiring, a separate control unit would need to be included to control these units.
Lastly, the power requirements are higher than single LED solutions because these units have seven times as many LEDs to power.

The last type of display unit under consideration is a programmable LED module.
One common example of this type of unit is the NeoPixel from Adafruit. \cite{led3}
These units provide many useful features like a unified programming interface with an internal driver which allows for full color and brightness control with a large number of pins.
One very interesting feature is the ability to tie multiple units together and control them all individually through a common bus.
Each module uses four pins to communicate with the controller.
Fully programmable brightness and red blue green color spectrum round out a tempting set of features.

The project team led to agree with the product suggestion provided by the client.
Programmable LED modules with internal drivers are the best solution for powering the clock display.
Unparalleled ease of use and flexibility fully meet the proposed feature set of the display including color schemes and variable brightness without requiring a standalone additional controller for the display lighting.
In order to get the most out of these units, the team has already acquired several samples to begin experimenting with to learn the API.

\subsection{Power Source}

Two separate avenues are being considered for powering the clock project.
The most simple approach would be a fixed permanent wall connection.
While this would work, most clocks that can function as wall clocks operate off of battery power to prevent the need for visually distracting wiring.

The final power specification isn’t yet known for the project but based on early projections and the hardware choices for LEDs and microcontroller, the target power supply needs to provide five volts at several amps.
The exact amperage isn’t known at this time due to the display resolution and subsequently the number of LEDs not yet being known.
This isn’t a primary concern as all of the following products and solutions for power have some degree of flexibility or come in multiple power ratings.

The first technology under consideration is a permanent fixed wall connection as the power supply.
Since the microcontroller and several of the best contenders for power supply regulating boards use micro USB, it would be possible to tap the existing range of micro USB wall adapters meant for charging android phones and products like the Raspberry Pi.
Exact power requirements aren’t a concern as these adapters exist in a wide range of amperage ratings and specifications.

The first potential battery based power solutions is also based on an existing range of hardware.
Like the five volt power adapters mentioned before, there exist a very wide range of five volt battery packs designed for use as portable phone chargers and universal usb power sources.
These portable battery packs come in a variety of dimensions and power capacities.
Of course these wouldn’t be the only answer for power but such packs can be charged via standard USB wall adapters which would be simple to include.

The other battery based solution being considered is to design a custom solution using an array of batteries and prebuilt voltage regulating hardware.
An example of this type of power supply setup can be seen in the BattBorg, an add on designed for the Raspberry Pi. \cite{power1}
This option would be the most flexible but would require the largest amount of hardware development to deploy.

Unlike other categories of the literature review, the only definite selection being made at this time is the use of a standard microUSB power source.
While battery power would provide an appealing feature for a wall clock, the feasibility of battery power is currently unknown as the LED arrangement and overall system power draw aren’t yet known.
Without such numbers, figuring out a battery based solution for power isn’t possible.
In addition, we have already reached an understanding with our client that battery power would be a stretch goal rather than a main focus of the project.

\subsection{Existing Software Libraries}

While the physical appearance of the clock is very important, all of the timekeeping functionality and the ability to display the time is powered by a software library running on the board.
In this case, the chosen board is an MPLAB Xpress IDE board which uses a combination of direct hardware control and c programming to control it.
Since the board supports C and C based assembly, the selection of software available is very large.
A homemade word clock has been done before many times before and we will be discussing the capabilities provided by three different software implementations of the word clock functionality.

The first version of word clock software is written in C for Ardruino by Doug Jackson and Scott Bezek.
Their software, released under the GNU General Public License, is most of a starting point than a library. \cite{software1}
This software provides nothing more than the core function of a word clock including predefined word sets and corresponding LED control, as well as simple controls for changing the time.
The library lacks any other advanced features and only drives a single color of LED.
Another setback is the almost complete lack of documentation for this software.

The second set of software under consideration is a more robust suite of clock control software from a project on the website Elektronika.
Also released under a permissive license, many additional features are included above and beyond the core clock functionality. \cite{software2}
Standout features include temperature sensor reading and temperature display support as well as a scrolling display of the date.
The other important feature of this software is a semblance of documentation.
While still sparse, the code is documented in a readable fashion.

The final set of clock software is from the QloneTwo team.
Released under the Apache license, this control software also written for Arduino is aimed at being a perfect copy of the function of the original word clock.
Nothing more than simple time support is included but an intriguing feature is strong support for button input. \cite{software3}
Other than this feature, the QloneTwo library doesn’t provide any additional functionality over the other two libraries.
This library also lacks any form of in depth documentation.

If faced with the choice of using only off the shelf existing hardware, the library from Elektronika is the most well documented and provides the most features which line up with project requirements.
Since the project focus is software design, the best course forward would be to take advantage of the useful bits of existing code under open licenses and expand it with a more flexible framework.
The core concept missing from all the software libraries that were reviewed is any ease in plugging additional features or display modes into the library.
To meet this goal and to facilitate various stretch goals, the best software choice is a new implementation based on the existing Elektronika implementation.

\subsection{Winter Term Updates}
The past term of development has led to changes in the power requirements for the project in addition to developments in terms of software support.

Power developments have centered around how much current is necessary for the lights.
Initial estimates for power requirements were high because the concept was that lights would be constantly on.
Advancements have been made in terms of controlling the lights which we have used to only ever have one light on at a time.
Because of this iterating process, the power requirements have dropped drastically to the point that a 5 volt feed at 2 amps from a power supply or USB source will be sufficient.
Because of this, battery power is still being considered for a wall mounted version of the clock.

Another major update to the project is related to software support.
The project has changed to using an Arduino board which has very broad software support.
The previous board didn't actually support any of the libraries listed above whereas the new board does.
In addition to supporting those libraries, other libraries have been found which have significantly moved the project along.
These include libraries for taking care of day light savings time and RTC control.

\subsection{Testing}
In an effort to keep things modern and hip, our team will be applying agile practices to our development cycle.
This method relies heavily on good testing practices, and with that in mind, we have a set of methods that we will use as we proceed forward.
The agile testing method we will be implementing is Lean Testing.
This in the spirit of keeping our testing accurate while not developing useless artifacts for after the project is done.
Since this is just a project and not a permanent product or company, without any further development in mind, making advanced test suites and the like are rather unnecessary.
In order to provide accurate lean testing, we will be pairing 1 team member as the tester, with two team members as developers for each unit test.
Hopefully the ones in the developer role at the time will be the ones who worked on the specific segment being tested.
This allows us to keep a very extensive testing method while we do it manually.
The project allows for this type of manual testing for most of our purposes, and the situations where we cannot manually test have been addressed in the design document.
Regarding our work schedule, we mostly will be meeting once a week, testing goals, making a week plan, and share-developing during said meetings.
This is essentially a big scrum and adds to the compatibility of our development practices going forward.

This in mind, we recognize that the Waterfall methodology is also a good fit for our project, as it seems to fall in line very well with the actual class structure.
The general steps for Waterfall are strict, and as follows: Gather document requirements, Design, Code and Unit Test, Perform system testing, Perform User acceptance testing, Fix Issues, and Deliver the product.
While this does fit very well in terms of the class structure, it falls inferior to our modified agile testing/development, due to the high variability in availability of the developers, and our client.
The clients presence is not required for the most part in Waterfall methodology, and we have decided to keep victor involved at essentially each iteration.
This of course means, our development leans much more to the modified agile style.

\section{Changes to Technology Review}
During the winter term we decided that we needed to change the microcontroller that we were using for our project.
This change came about because of road blocks and board development issues we didn't foresee when originally reviewing the product.
Here is our update to the Technology Review that we added during winter term.
\subsection{Micro Controller Winter Update}
This term we started working with our micro controller and ran into a few issues that made us rethink the choice of using this board.
The main two issues that caused us to rethink our board choice was figuring out the IDE and library support for this board.

The IDE of this board on the surface is nice because it is web based and many examples that will help with learning how to use the board.
But after further exploration we discovered many sections of code were auto generated and made is difficult for us to read and follow what was going on.

The other main issue was the library support for this board. We could not find library support for this type of board.
To get around this issue we would have had to written our own libraries or set up the existing libraries for other board types and change many defined variables and globals to what work with our board and the pins assignments on our current board.

When we ran into these issues and found little help on the internet we started to research other board options that would help us get moving forward and writing code for our project.
Arduinos were a readily available option that would be better suited for our project. We choose to use the Keyestudio's Arduino Uno R3 board because it addressed the issues with had with our old board and more.

The KeyeStudio Arduino Uno R3 runs off a ATmega328 core which has a large amount of supported libraries that would help us to easily start working with our RTC and LED strips.
The libraries we found for RTC and LED interaction were well written and had many examples and tutorials on how to get them setup and running.
The concern about the IDE was also solved with the switch to an Arduino.
We are now using the Arduino IDE which has many examples, wikis, and forums online that will help us trouble shoot issues and roadblocks that we run into when getting hardware to interact, code to compile, and flashing files onto the board.

Along with solving out two concerns with the MPBLABXpress the Arduino also brings plug and play functionality and easier ability to define and change the pins that are being used for our RTC and LED strips.
The added benefits of being able to plug in components with wires instead of soldering, ability to easily change what pins are used for communication, and addressing our concerns of the old board make the KeyeStudio Arduino Uno R3 a great choice for our new board moving forward.

\section{Weekly Blog Posts}
\subsection{Fall}
\subsubsection{Week 3}
\paragraph{Tristan}
Hello all who will read this.
Over our first week being officially on the project we were able to successfully draft out our project abstract as well as an agreement of project goals/deliverables with the client. Our Client Victor Hsu seems like a great person to be working with and is very quick to communicate and be helpful where he can. We received the Mikrocontroller boards in our first meeting with him, as well as the arduino clock module that we will be using to manage time keeping. The boards look to be a humble beginning, but before long they will turn out to be something great. Over the next few weeks Victor will be receiving some LED strips which will be doing the basic backlighting for the end product.
Overall for week one, we're just getting started so there isn't much to update, but in short it appears we've got a good team and a cool project to work on, so I'm looking forward to seeing the progress.
~Tristan
\paragraph{Taz}
Welcome to the first blog from the One clock to rule them all project. Some of the other group members have already talked about what we accomplished this past week so I wanted to take a little time to talk about our dreams for this project.

The goal for this project seems relatively simple: build a clock with a slightly unusual way of displaying time. But there is so much more beyond that. Most of our ideas are related to stretch goals and involve the idea of turning the 11x11 or 12x12 grid of letters into a pseudo screen that uses each letter as a pixel. Once we have a library of functionality to support that, the sky is really the limit.

Some initial ideas about what we could do with this:

A ticker tape style print out of the time
A ticker tape display of any custom message or associating messages with specific times
Basic games like pong
Using time formulas and the multicolor nature of the leds to make them change with the time of day
...and so much more. Already in the initial meeting our client expressed interest in all these types of theoretical functionality. Between this and the fact that everybody in the group is competent and excited about the project, I think we will end up with something great by the time expo rolls around.

~Taz
\paragraph{Scott}
Welcome to our blog for the One Clock to Rule Them All capstone project!

We will be creating a clock that will tell time using words.

This was the first week and we were able to meet our mentor/project leader Victor Hsu. He gave us each a MPLAB Express PIC16F18855 Evaluation Board to use for our clocks. The board has a IDE that you can code in similar to Eclipse in layout. I was able to run some of the basic tutorials using the LED's and turnable knob built into the board and will be trying out some other small projects with the board using LED's this week. Once we are able to get the LED strips we will be using for the clock we will be able to do more things with the board and will go through and learn about what we will need to power and connect up to our board to use the LED strips. I am looking forward to the design of the box to hold the clock and working with different materials to construct it.

~Scott
\subsubsection{Week 4}
\paragraph{Tristan}
This week was a semi productive week. We were mostly working on getting our requirements document together, and with some effort we were able to do so. For some reason, upon reviewing with the instructors we had to pretty much scrape away all of the IEEE formatting in order to get the correct formatting for this document. To say the least, this process was awful and time consuming, involving some complicated and non=intuitive syntax. I want to believe Kevin when he says LaTex is great, but this event has pushed me towards the opposing opinion. Aside from that we met with the client again and got the remaining two RTC's and some variety of LED strips. This pretty allows us to begin playing with the mikrocontroller some more. Moving forward, we'll be looking for feedback on our requirements document, attempting to fiddle with the hardware, and awaiting the next assignment!

~Tristan
\paragraph{Taz}
This past week has been a pretty slow week on the project. In the wake of feedback from McGrath, our group has started work on another revision of our Problem Statement. We consider ourselves in a reasonable position because our document was already somewhat solid.

The only large change we are still discussing is how to phrase the requirement that our clock is only expected to work if hooked up to a grid of letters that provides "enough" letters. Enough is defined as having the necessary number of copies of each letter that we can concurrently spell any of the necessary subsets of words that describe all the times in the day. This is a very abstract requirement but without it, we don't stand a chance of actually spelling out all the necessary times.

We are working to rephrase this requirement because it was are only requirement that concerned whoever reviewed our document. They were concerned that it was more of an aesthetic requirement which should be avoided because it can be hard to grade completion or satisfaction for that type of requirement.
\paragraph{Scott}
This week we received feedback on our project proposal document. We will be adding to the sections that need to be addressed and send it back to our contact, Victor to get his signature on the changed that we have made to the document. Also this week I experimented more with the board and learn a bit more about how to use the logic board that we will be using for this clock.

This next work we will be doing is on the requirements document. This project will take more time and need more feedback and more writing to complete it. This will be due this coming Friday, the 28th of October.
\subsubsection{Week 5}
\paragraph{Tristan}
Without much to report this will be a fairly bland update. This week we outlined our requirements document, and nailed down some more specifics of the end product with our client. More and more the idea of the clock is coming to fruition and i'm excited to see it come together. We also met with Jon dodge, our TA and he seems like cool dude. Other than that, we haven't had much progress to report, things are still in the early phase here and there's a lot to learn. I've been playing with the board when I can, but time is limited so perhaps next week i'll be able to explore more things in depth.
\paragraph{Taz}
The past week hasn't been all that interesting in therms of project progress. The group has continue grinding through the strict documentation requirements which is surprisingly difficult for our project. For groups with a more traditional or research oriented project, the requirements document spec works pretty well. For our project, it feels like restating the phrase "we are building a fancy clock" over and over and over...

As far as real progress is concerned, not much has changed in terms of our understanding of the hardware but we will be sitting down with the client this coming week to talk more about the lights. The strips of programmable LEDs that will power the clock face come in various spacings. We currently only have one spacing to work with but several more arrived in the mail this past week so we should be able to start experimenting with those shortly.
\paragraph{Scott}
This week we finalized our project proposal and got a signature of approval for the changes that we made. We also started and completed a draft of the Requirement Document and turned that in this Friday. We were a little unsure about how to write some of the sections and will hopefully get some feedback so we can do a better job for the final copy of the Requirements Document.
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

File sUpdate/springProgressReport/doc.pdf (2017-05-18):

## CS CAPSTONE PROGRESS REPORT

### MAY 15, 2017

# ONE CLOCK TO RULE THEM ALL

PREPARED FOR

# OREGON STATE UNIVERSITY

### DR. VICTOR HSU

PREPARED BY

# GROUP 57

### TASMAN THENELL TRISTAN HARI SCOTT METZSCH

Abstract

The purpose of this document is to discuss the progress of the One Clock to Rule Them All project and what our team has done during the spring term. Included is an explanation of each document updated during this period of time and a summary of the progress made during each week of the term. In addition, this process is reflected in retrospective which discusses challenges and difficulties as well as progress.

CONTENTS

1 | Project Purpose and Goals | 2
2 | Current State of project | 2
3 | Remaining Work | 3
4 | Impeding Factors | 4
5 | Code Samples | 5
6 | Project Pictures | 6
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

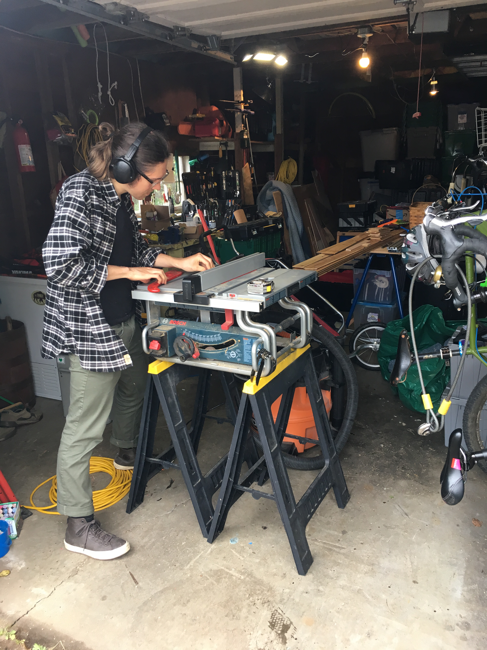
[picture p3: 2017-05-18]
sUpdate/springProgressReport/exPics/scott.JPG

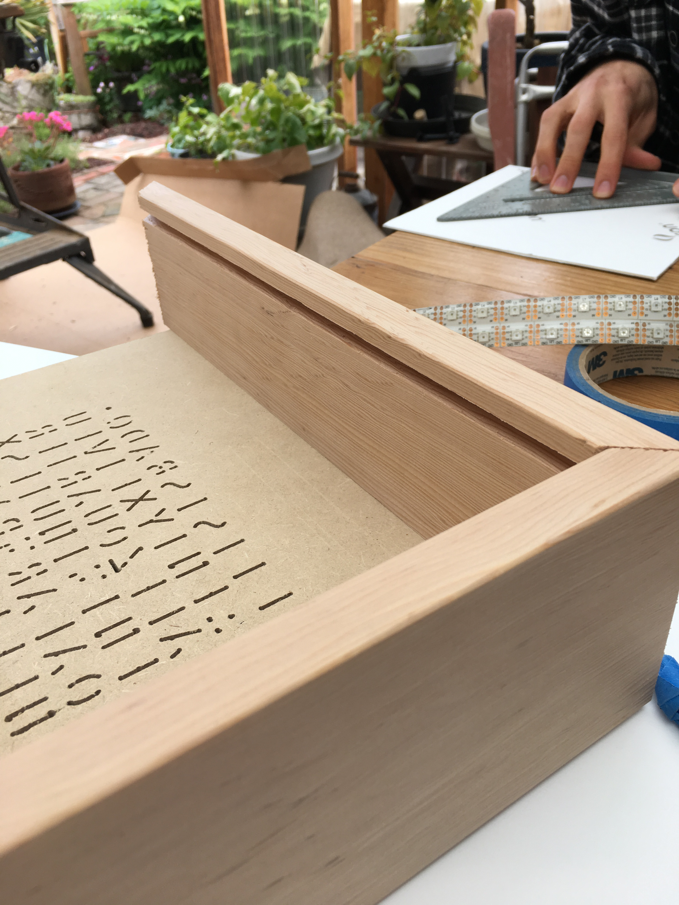
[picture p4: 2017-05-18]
sUpdate/springProgressReport/exPics/wood.JPG

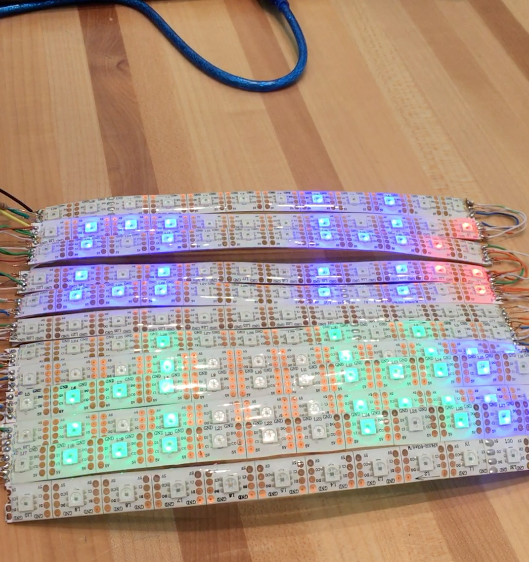
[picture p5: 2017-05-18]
sUpdate/springProgressReport/exPics/lights.png

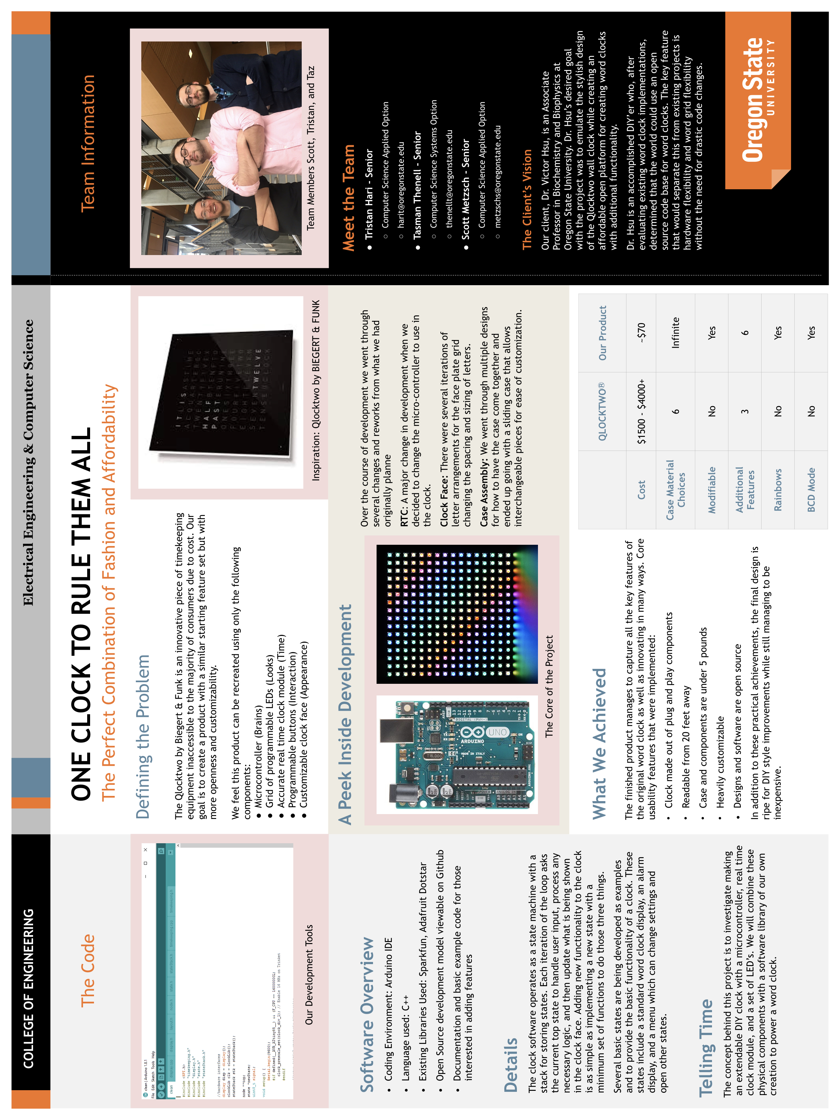
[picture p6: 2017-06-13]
finalPaper/graphics/FixedTeam57.jpeg

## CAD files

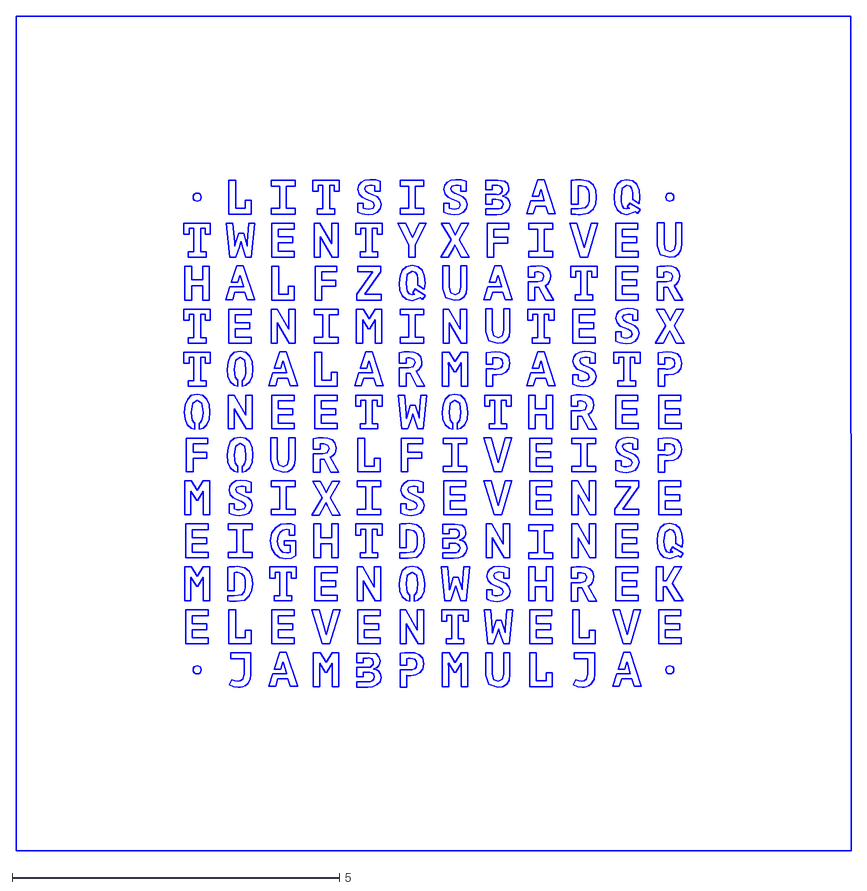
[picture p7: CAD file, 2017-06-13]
cadDrawings/ClockFaceFinal.dxf
12.7 x 12.7

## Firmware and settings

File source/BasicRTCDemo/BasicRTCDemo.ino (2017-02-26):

/******************************************************************************
DS3234_RTC_Demo.ino
Jim Lindblom @ SparkFun Electronics
original creation date: October 2, 2016
https://github.com/sparkfun/SparkFun_DS3234_RTC_Arduino_Library

Configures, sets, and reads from the DS3234 real-time clock (RTC).

Resources:
SPI.h - Arduino SPI Library

Development environment specifics:
Arduino 1.6.8
SparkFun RedBoard
SparkFun Real Time Clock Module (v14)
*****************************************************************************/
#include <SPI.h>
#include <SparkFunDS3234RTC.h>

// Comment out the line below if you want month printed before date.
// E.g. October 31, 2016: 10/31/16 vs. 31/10/16
#define PRINT_USA_DATE

//////////////////////////////////
// Configurable Pin Definitions //
//////////////////////////////////
#define DS13074_CS_PIN 10 // DeadOn RTC Chip-select pin
//#define INTERRUPT_PIN 2 // DeadOn RTC SQW/interrupt pin (optional)

void setup() 
{
  // Use the serial monitor to view time/date output
  Serial.begin(9600);
#ifdef INTERRUPT_PIN // If using the SQW pin as an interrupt
  pinMode(INTERRUPT_PIN, INPUT_PULLUP);
#endif

  // Call rtc.begin([cs]) to initialize the library
  // The chip-select pin should be sent as the only parameter
  rtc.begin(DS13074_CS_PIN);
  //rtc.set12Hour(); // Use rtc.set12Hour to set to 12-hour mode

  // Now set the time...
  // You can use the autoTime() function to set the RTC's clock and
  // date to the compiliers predefined time. (It'll be a few seconds
  // behind, but close!)
  rtc.autoTime();
  // Or you can use the rtc.setTime(s, m, h, day, date, month, year)
  // function to explicitly set the time:
  // e.g. 7:32:16 | Monday October 31, 2016:
  //rtc.setTime(16, 32, 7, 2, 31, 10, 16);  // Uncomment to manually set time

  // Update time/date values, so we can set alarms
  rtc.update();
  // Configure Alarm(s):
  // (Optional: enable SQW pin as an intterupt)
  rtc.enableAlarmInterrupt();
  // Set alarm1 to alert when seconds hits 30
  rtc.setAlarm1(30);
  // Set alarm2 to alert when minute increments by 1
  rtc.setAlarm2(rtc.minute() + 1);
}

void loop() 
{
  static int8_t lastSecond = -1;
  
  // Call rtc.update() to update all rtc.seconds(), rtc.minutes(),
  // etc. return functions.
  rtc.update();

  if (rtc.second() != lastSecond) // If the second has changed
  {
    printTime(); // Print the new time
    
    lastSecond = rtc.second(); // Update lastSecond value
  } 

  // Check for alarm interrupts
#ifdef INTERRUPT_PIN
  // Interrupt pin is active-low, if it's low, an alarm is triggered
  if (!digitalRead(INTERRUPT_PIN))
  {
#endif
    // Check rtc.alarm1() to see if alarm 1 triggered the interrupt
    if (rtc.alarm1())
    {
      Serial.println("ALARM 1!");
      // Re-set the alarm for when s=30:
      rtc.setAlarm1(30);
    }
    // Check rtc.alarm2() to see if alarm 2 triggered the interrupt
    if (rtc.alarm2())
    {
      Serial.println("ALARM 2!");
      // Re-set the alarm for when m increments by 1
      rtc.setAlarm2(rtc.minute() + 1, rtc.hour());
    }
#ifdef INTERRUPT_PIN
  }
#endif
}

void printTime()
{
  Serial.print(String(rtc.hour()) + ":"); // Print hour
  if (rtc.minute() < 10)
    Serial.print('0'); // Print leading '0' for minute
  Serial.print(String(rtc.minute()) + ":"); // Print minute
  if (rtc.second() < 10)
    Serial.print('0'); // Print leading '0' for second
  Serial.print(String(rtc.second())); // Print second

  if (rtc.is12Hour()) // If we're in 12-hour mode
  {
    // Use rtc.pm() to read the AM/PM state of the hour
    if (rtc.pm()) Serial.print(" PM"); // Returns true if PM
    else Serial.print(" AM");
  }
  
  Serial.print(" | ");

  // Few options for printing the day, pick one:
  Serial.print(rtc.dayStr()); // Print day string
  //Serial.print(rtc.dayC()); // Print day character
  //Serial.print(rtc.day()); // Print day integer (1-7, Sun-Sat)
  Serial.print(" - ");
#ifdef PRINT_USA_DATE
  Serial.print(String(rtc.month()) + "/" +   // Print month
                 String(rtc.date()) + "/");  // Print date
#else
  Serial.print(String(rtc.date()) + "/" +    // (or) print date
                 String(rtc.month()) + "/"); // Print month
#endif
  Serial.println(String(rtc.year()));        // Print year
}

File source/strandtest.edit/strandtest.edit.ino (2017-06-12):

// Because conditional #includes don't work w/Arduino sketches...
#include <SPI.h>         // COMMENT OUT THIS LINE FOR GEMMA OR TRINKET
#include <SparkFunDS3234RTC.h>
//#include <avr/power.h> // ENABLE THIS LINE FOR GEMMA OR TRINKET
#include <Adafruit_DotStar.h>
#include <TimeLib.h>
#define NUMPIXELS 14 // Number of LEDs in strip
#define DS13074_CS_PIN 10 // DeadOn RTC Chip-select pin
#define INTERRUPT_PIN 2 // DeadOn RTC SQW/interrupt pin (optional)

// Here's how to control the LEDs from any two pins:
#define DATAPIN    4 //RED WIRE
#define CLOCKPIN   5 //GREEN WIRE
#define RTC        0
Adafruit_DotStar strip = Adafruit_DotStar(
  NUMPIXELS, DATAPIN, CLOCKPIN, DOTSTAR_BRG);
// The last parameter is optional -- this is the color data order of the
// DotStar strip, which has changed over time in different production runs.
// Your code just uses R,G,B colors, the library then reassigns as needed.
// Default is DOTSTAR_BRG, so change this if you have an earlier strip.

// Hardware SPI is a little faster, but must be wired to specific pins
// (Arduino Uno = pin 11 for data, 13 for clock, other boards are different).
//Adafruit_DotStar strip = Adafruit_DotStar(NUMPIXELS, DOTSTAR_BRG);
uint8_t mode;
uint8_t curr_pixel;
uint32_t brightness;
uint8_t binaryMonth;
uint8_t binaryDay;
//uint8_t day;
//uint8_t month;
//uint32_t year;

void messWithLEDS();

void setup() {
   Serial.begin(9600);

#if defined(__AVR_ATtiny85__) && (F_CPU == 16000000L)
  clock_prescale_set(clock_div_1); // Enable 16 MHz on Trinket
#endif
  curr_pixel = 0;
  mode = 4;
  //brightness = 0;
  if(RTC){
    #ifdef INTERRUPT_PIN // If using the SQW pin as an interrupt
      pinMode(INTERRUPT_PIN, INPUT_PULLUP);
    #endif
    rtc.begin(DS13074_CS_PIN);
    //rtc.autoTime();
    rtc.setTime(0, 39, 13, 2, 31, 10, 16);
    rtc.update();
    rtc.enableAlarmInterrupt();
  }
  else{
    //day = 17;
    //month = 6;
    //year = 2017;
    setTime(0, 0, 0, 12, 2, 2017);
  }
  strip.begin(); // Initialize pins for output
  strip.setBrightness(255);
  strip.show();  // Turn all LEDs off ASAP
}

// Runs 10 LEDs at a time along strip, cycling through red, green and blue.
// This requires about 200 mA for all the 'on' pixels + 1 mA per 'off' pixel.

int      head  = 0, tail = NUMPIXELS; // Index of first 'on' and 'off' pixels
uint32_t color = 0x000000;
uint8_t r = 0xFF; 
uint8_t g = 0x00; 
uint8_t b = 0x00;
uint32_t list[NUMPIXELS];

void loop(){  
  rtc.update();
  //handleInput();
  switch(mode){
  case 0: //timeDisplayWords();
          break;
  case 1: //timeDisplayTicker();
          break;
  case 2: //dateTicker();
          break;
  case 3: //alarmTrigger();
          break;
  case 4: rainbowPuke();
          break;
  case 5: hackyMinSec();
          break;
  }
}

void hackyMinSec(){
  strip.clear();
  strip.setBrightness(255);
  uint32_t colorMin = 0xFF0000; //Green
  uint32_t colorSec = 0x00FF00; //Red
  int mins;
  int secs;
  if(RTC){
    mins = rtc.hour();
    secs = rtc.minute(); 
  }
  else{
    mins = minute();
    secs = second(); 
  }
  int counter = 5;
  int i = 32;

  Serial.print("Min: ");
  Serial.print(mins);
  Serial.print(" Sec: ");
  Serial.print(secs);
  Serial.println();
  
  
  while(counter >= 0){
    if(mins - i >= 0){
      strip.setPixelColor(counter+6, colorMin);
      strip.show();
      mins = mins - i;   
    } else {
      strip.setPixelColor(counter+6, 0x000000);
      strip.show();
    } if(secs - i >= 0){
      strip.setPixelColor(counter, colorSec);
      strip.show();
      secs = secs - i;
    } else {
      strip.setPixelColor(counter, 0x000000);
      strip.show();
    }
    i = i / 2;
    counter--;
  } 
}

void rainbowPuke() {
  strip.clear();
  //color = Color(r, g, b); //Convert separate uint8_t r, g, and b into single uint32_t
  color = ((uint32_t)r << 16) | ((uint32_t)g << 8) | b; //Taken from Adafruit_DotStay.h
  
  for(int i = NUMPIXELS - 1; i > 0 ; i--){ 
    strip.setPixelColor(i, list[i-1]); //Changes LED color to color of previous LED
    list[i] = list[i - 1]; //Changes LED color in list to color of previous LED
  }
  strip.setPixelColor(0, color); //Changes first LED to new color
  list[0] = color; //Stores new color to first position of LED list
  
  strip.setPixelColor(curr_pixel, color);
  strip.setBrightness(brightness / 16);
  strip.show();
  //delay(1);

  //Logic to loop through colors
  if(r == 255 && b == 0 && g < 255){
    g += 1;
  }else if(g == 255 && b == 0 && r > 0){
    r -= 1;
  }else if(r == 0 && g == 255 && b < 255){
    b += 1;
  }else if(b == 255 && r == 0 && g > 0){
    g -= 1;
  }else if(g == 0 && b == 255 && r < 255){
    r += 1;
  }else if(r == 255 && g == 0 && b > 0){
    b -= 1;
  }

  brightness++;
  brightness = brightness % 4095;

  curr_pixel++;
  if(curr_pixel >= NUMPIXELS){
    curr_pixel = 0;
  }
  
}

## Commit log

2016-11-15 Updated paragraphs to be 1 sentence per line for RTC, Materials, and Fabrication sections
2016-12-02 Added one of the viewpoints, but im tired sorry boiz see ya tomorrow
2016-12-06 Created new folder for progress report paper, powerpoint, and presentation video.
2016-12-07 updated current status and progress sections
2017-02-08 Created source code folder for arduino code. Added led rainbow effect code to source folder
2017-02-08 Added libraries folder for the different arduino libraries used for this project. Also added README.txt file to libraries folder with links to current versions of libraries
2017-02-13 Reorganized source folder so you don't have to create folder each time you want to open code in Arduino IDE
2017-02-16 added winter section for tech review power and library sections
2017-02-16 Wrote current state of project for winter progress report
2017-03-13 Testing clean version of code with state machine
    Test code written from the ground up with statemachine in mind.
2017-04-17 display code tweaks and demo state for testing clockface prints
2017-04-24 button abstraction and updates to testing state
2017-05-16 Added template and goals section to spring update
2017-05-18 Passes Arduino Compiler and Fixed Menu Construct
2017-05-26 V2 of Memory optimization
    Down to 37% passive usage. Eliminated remaining strings, added more
    __FlashStringHelper overloads, and tweaked serial buffer size. This last
    change is annoying as it takes modifying arduino files but it saves 96
    bytes of ram.
2017-06-13 Added more to the physical case design of project documentation
2017-06-13 Added dxf file for final clock face cnc path.
    [ClockFaceFinal.dxf]
2017-10-13 renamed ino file for arduino ide
